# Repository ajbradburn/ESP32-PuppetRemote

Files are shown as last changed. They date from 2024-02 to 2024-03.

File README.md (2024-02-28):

The goal is to create a remote control for a puppet.

1. Direct communication between two ESP devices via ESP-NOW.
2. Playing sound upon trigger.
3. Control servo to articulate eye lids.
4. Control motor to retract wings.

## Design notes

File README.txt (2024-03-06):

The goal is to create a remote control for a puppet.

1. Direct communication between two ESP devices via ESP-NOW.
2. Playing sound upon trigger.
3. Control servo to articulate eye lids.
4. Control motor to retract wings.

Implemented with Micropython
https://micropython.org/download/ESP32_GENERIC_S3/

Example Ampy Commands: ampy -p /dev/ttyACM0 -b 115200 put receiver.py main.py

-: Setup Environment
-- THIS --
sudo apt install python3-venv
python3 -m venv .venv
source .venv/bin/activate
pip3 install adafruit-ampy
pip3 install esptool
-- OR --
sudo apt install python3 python3-pip
sudo pip3 install adafruit-ampy --break-system-packages
sudo pip3 install esptool –break-system-packages
-- THEN --
python3 -m esptool --port /dev/ttyACM0 erase_flash
python3 -m esptool --chip esp32s3 --port /dev/ttyACM0 write_flash -z 0 ESP32_GENERIC_S3-SPIRAM_OCT-20240222-v1.22.2.bin
ampy -p /dev/ttyACM0 -b 115200 put receiver.py main.py

To reset: -> Connect via serial port. picocom -b 115200 /dev/ttyACM0 -> At the terminal, type the following:
import machine
machine.reset()

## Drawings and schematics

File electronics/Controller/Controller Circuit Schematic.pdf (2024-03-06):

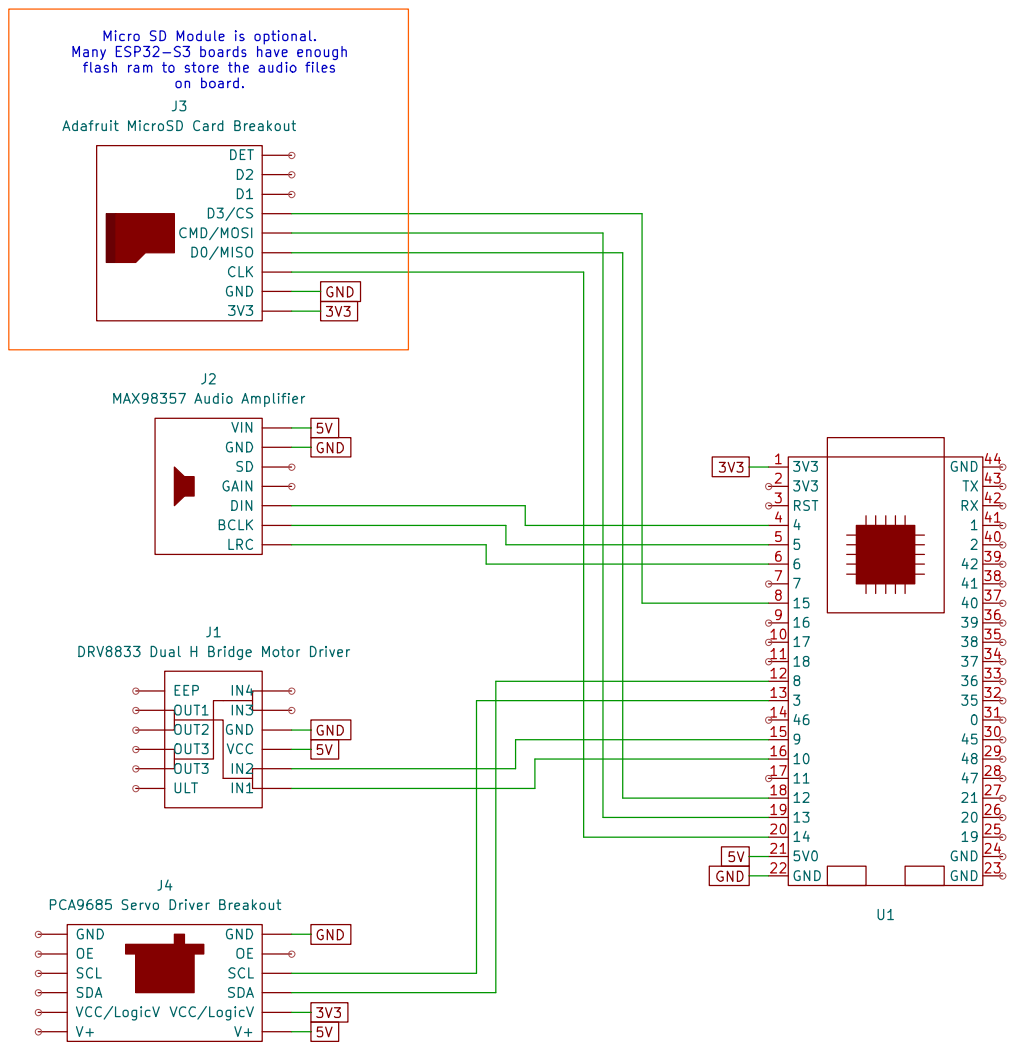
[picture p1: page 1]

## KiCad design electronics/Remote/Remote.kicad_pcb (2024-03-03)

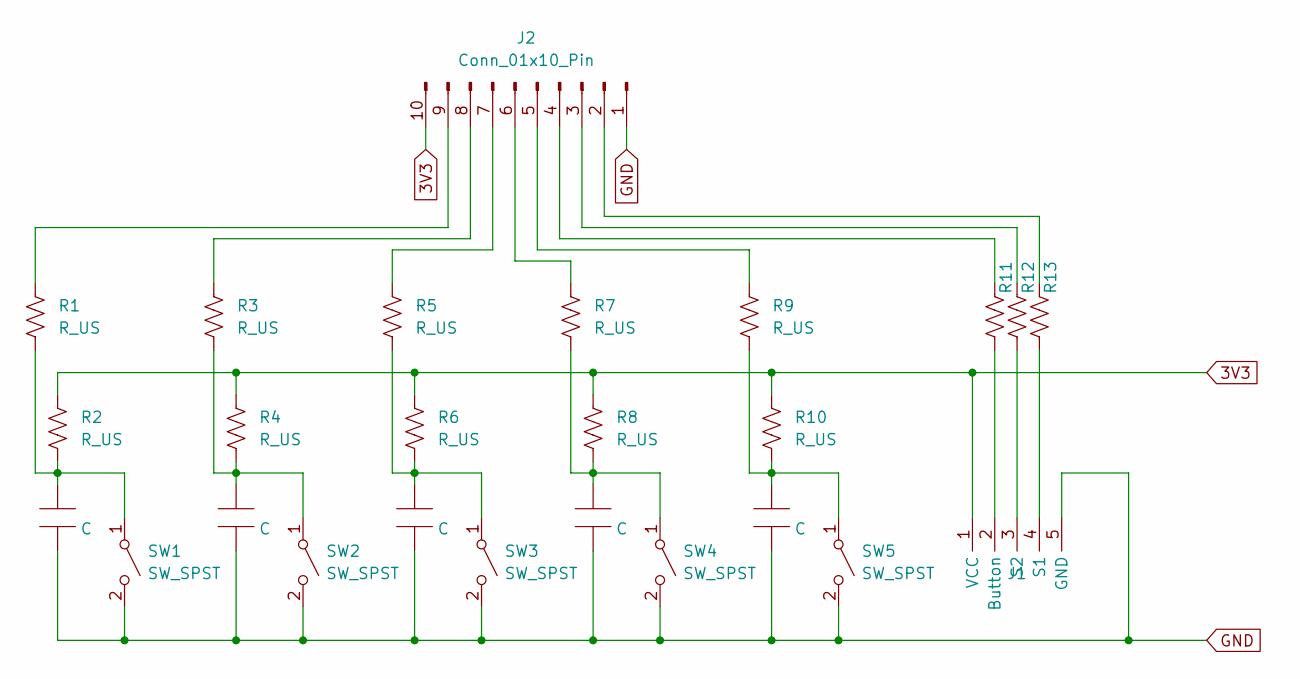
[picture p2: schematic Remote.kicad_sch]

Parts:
C1, C2, C3, C4, C5: C; C_MicroMELF_MMU-0102
J1: PinHeader_1x05_P2.54mm_Vertical
J2: Conn_01x10_Pin; PinHeader_1x10_P2.54mm_Vertical
R1, R2, R3, R4, R5, R6, R7, R8, R9, R10, R11, R12, R13: R_US; R_0805_2012Metric
SW1, SW2, SW3, SW4, SW5: SW_SPST; SW_Push_1P1T_NO_6x6mm

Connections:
3V3: J1.1 (VCC), J2.10, R2.1, R4.1, R6.1, R8.1, R10.1
GND: C1.1, C2.1, C3.1, C4.1, C5.1, J1.5 (GND), J2.1, SW1.2 (B), SW2.2 (B), SW3.2 (B), SW4.2 (B), SW5.2 (B)
unnamed: J1.2 (Button), R11.2
unnamed: J1.4 (S1), R13.2
unnamed: J1.3 (S2), R12.2
unnamed: J2.2, R13.1
unnamed: J2.3, R12.1
unnamed: J2.4, R11.1
unnamed: J2.5, R9.1
unnamed: J2.6, R7.1
unnamed: J2.7, R5.1
unnamed: J2.8, R3.1
unnamed: J2.9, R1.1
unnamed: C1.2, R1.2, R2.2, SW1.1 (A)
unnamed: C2.2, R3.2, R4.2, SW2.1 (A)
unnamed: C3.2, R5.2, R6.2, SW3.1 (A)
unnamed: C4.2, R7.2, R8.2, SW4.1 (A)
unnamed: C5.2, R9.2, R10.2, SW5.1 (A)

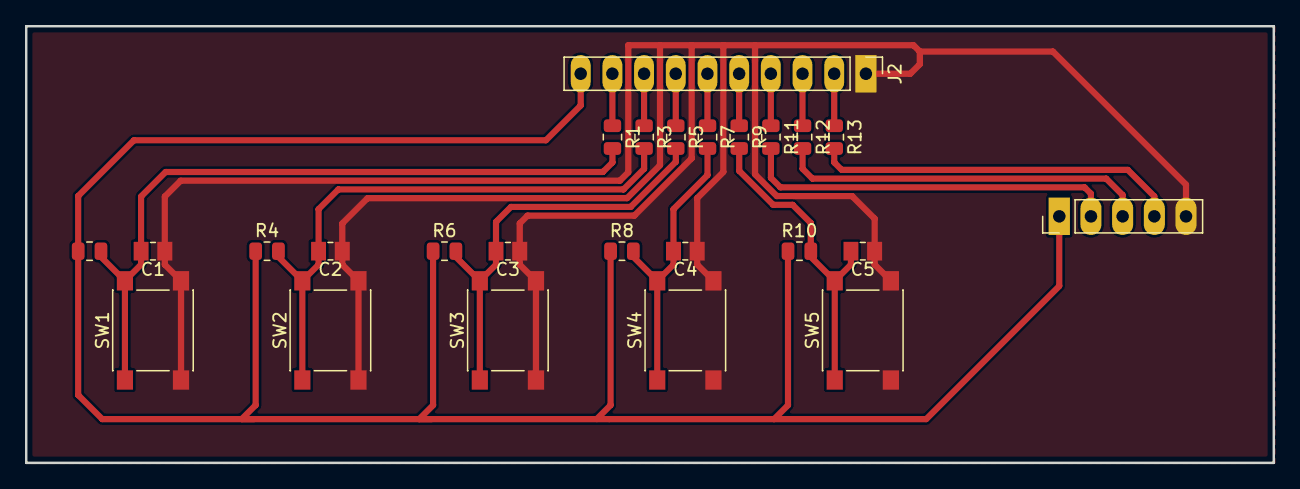
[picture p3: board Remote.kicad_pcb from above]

Board: 2 copper layers, 100.0 x 35.0 mm, 25 parts (0 on the bottom side), 18 nets.

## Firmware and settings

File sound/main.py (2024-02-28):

# The MIT License (MIT)
# Copyright (c) 2020 Mike Teachman
# https://opensource.org/licenses/MIT

# Purpose:
# - read 16-bit audio samples from a mono formatted WAV file on SD card
# - write audio samples to an I2S amplifier or DAC module 
#
# Sample WAV files in wav_files folder:
#   "taunt-16k-16bits-mono.wav"
#   "taunt-16k-16bits-mono-12db.wav" (lower volume version)
#
# Hardware tested:
# - MAX98357A amplifier module (Adafruit I2S 3W Class D Amplifier Breakout)
# - PCM5102 stereo DAC module
#
# The WAV file will play continuously until a keyboard interrupt is detected or
# the ESP32 is reset
  
from machine import I2S
from machine import SDCard
from machine import Pin
import uos

#======= USER CONFIGURATION =======
#WAV_FILE = 'chimes.wav'
WAV_FILE = 'snake.wav'
#WAV_FILE = 'chimes-22050.wav'
SAMPLE_RATE_IN_HZ = 44100
#======= USER CONFIGURATION =======

bck_pin = Pin(5) 
ws_pin = Pin(6)  
sdout_pin = Pin(4)

# channelformat settings:
#     mono WAV:  channelformat=I2S.ONLY_LEFT
audio_out = I2S(
    1, 
    sck=bck_pin, ws=ws_pin, sd=sdout_pin, 
    mode=I2S.TX,
    bits=16,
    format=I2S.MONO, 
    rate=SAMPLE_RATE_IN_HZ,
    ibuf=1024
    )

# configure SD card:
# See [docs](https://docs.micropython.org/en/latest/library/machine.SDCard.html#esp32) for
# recommended pins depending on the chosen slot.
#   slot=2 configures SD card to use the SPI3 controller (VSPI), DMA channel = 2
#   slot=3 configures SD card to use the SPI2 controller (HSPI), DMA channel = 1
sd = SDCard(slot=3, sck=Pin(14), mosi=Pin(13), miso=Pin(12), cs=Pin(15))
print(sd)
uos.mount(sd, "/sd")
import os
print(os.listdir("/sd"))
wav_file = '/sd/{}'.format(WAV_FILE)
wav = open(wav_file,'rb')

# advance to first byte of Data section in WAV file
pos = wav.seek(44) 

# allocate sample arrays
#   memoryview used to reduce heap allocation in while loop
wav_samples = bytearray(1024)
wav_samples_mv = memoryview(wav_samples)
audio_out.shift

print('Starting')
# continuously read audio samples from the WAV file 
# and write them to an I2S DAC
try:
    while True:
        num_read = wav.readinto(wav_samples_mv)
        if num_read == 0:
            break
        num_written = 0
        while num_written < num_read:
            num_written += audio_out.write(wav_samples_mv[num_written:num_read])
except:
    print('caught exception {} {}'.format(type(e).__name__, e))


'''
while True:
    try:
        num_read = wav.readinto(wav_samples_mv)
        num_written = 0
#        # end of WAV file?
        if num_read == 0:
#            # advance to first byte of Data section
            pos = wav.seek(44) 
        else:
#            # loop until all samples are written to the I2S peripheral
            while num_written < num_read:
                num_written += audio_out.write(wav_samples_mv[num_written:num_read])
    except (KeyboardInterrupt, Exception) as e:
        print('caught exception {} {}'.format(type(e).__name__, e))
        break
'''
    
wav.close()
uos.umount("/sd")
sd.deinit()
audio_out.deinit()
print('Done')

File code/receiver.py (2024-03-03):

import network
import espnow

import ubinascii
print('Device MAC Address:')
print(network.WLAN().config('mac'))
print(ubinascii.hexlify(network.WLAN().config('mac'),':').decode())

from machine import I2C, Pin, I2S, SDCard, Timer
from servo import Servos
import time
from uos import mount, umount
from os import listdir
from time import ticks_ms, ticks_diff
from math import fabs

# Start ESP NOW
# A WLAN interface must be active to send()/recv()
sta = network.WLAN(network.STA_IF)
sta.active(True)

e = espnow.ESPNow()
e.active(True)
# End ESP NOW

# Start Servo Config
# Connect to the PCA9685 servo driver.
servo_disable_time = None

i2c = I2C(0, scl=3, sda=8)
ser = Servos(i2c, address=0x40)
ser.position(0, 0)
print(ser) # CRITICALLY IMPORTANT. This print statement enables I2S to work properly. Some combination of the i2c assignment, and then a variable assignemtn afterwards makes the I2S sound terrible. Simply printing the variable resolves the issue...
# End Servo

# Start Motor Config
# Configure the forward and reverse pins.
motor_disable_time = None

mf = Pin(9, Pin.OUT) # Motor Forward
mb = Pin(10, Pin.OUT) # Motor Backward
# End Motor

# Start Sound Config
current_file = None
BUFFER_SIZE = 10000

# Configure the I2S connection to the Max98357A audio amplifier.
bclk = Pin(5) # Clock Pin
lrc = Pin(6) # Channel Select Pin
din = Pin(4) # Data Pin

audio_out = I2S(
    1, 
    sck=bclk, ws=lrc, sd=din, 
    mode=I2S.TX,
    bits=16,
    format=I2S.MONO, 
    rate=44100,
    ibuf=BUFFER_SIZE
    )

# Start SD Card
# Connect to the SD card reader via SPI.
sd = SDCard(slot=3, sck=Pin(14), mosi=Pin(13), miso=Pin(12), cs=Pin(15))
mount(sd, "/sd")
#print(os.listdir("/sd"))

def blink():
    global servo_disable_time
    if servo_disable_time == None:
        servo_disable_time = ticks_ms() + 1000
        ser.position(0, 180)
    else:
        if servo_disable_time < ticks_ms():
            servo_disable_time = None
            ser.position(0, 0)

def flap():
    global motor_disable_time
    if motor_disable_time == None:
        motor_disable_time = ticks_ms() + 1000
        mf.value(1)
        print('Starting Flap')
    elif motor_disable_time < ticks_ms():
        if mf.value():
            motor_disable_time = ticks_ms() + 1000
            mf.value(0)
            mb.value(1)
            print('Reversing Flap')
        elif mb.value():
            motor_disable_time = None
            mb.value(0)
            print('Done Flapping')
        else:
            print('Already flapping.')

def i2s_callback(arg):
    global current_file
    global BUFFER_SIZE
    wav_samples = bytearray(BUFFER_SIZE)
    wav_samples_mv = memoryview(wav_samples)
    num_read = current_file.readinto(wav_samples_mv)
    if num_read == 0:
        audio_out.irq(None)
        current_file.close()
        current_file = None
    else:
        audio_out.write(wav_samples_mv[:num_read])

def playAudio(file):
    global current_file
    global BUFFER_SIZE
    # If the audio file has a value, we are going to abort, and let it finish.
    if current_file != None:
        return

    # Open the file and seek data.
    wav_file = '/sd/{}'.format(file)
    current_file = open(wav_file,'rb')
    pos = current_file.seek(44) 

    # Allocate audio buffer.
    #   memoryview used to reduce heap allocation in while loop
    wav_samples = bytearray(BUFFER_SIZE)
    wav_samples_mv = memoryview(wav_samples)
    #audio_out.shift
    num_read = current_file.readinto(wav_samples_mv)
    audio_out.irq(i2s_callback)
    audio_out.write(wav_samples_mv[:num_read])

def upkeep():
    if servo_disable_time != None:
        blink()
    if motor_disable_time != None:
        flap()

# Application Loop
while True:
    upkeep()

    host, msg = e.recv(0)
    if msg:             # msg == None if timeout in recv()
        #print(host, msg)
        command = msg.decode('utf-8')
        if msg == b'8':
            print('Play Audio')
            playAudio('snake.wav')
        elif msg == b'3':
            print('Blink')
            blink()
        elif msg == b'46':
            print('Flap Wings')
            flap()
        elif msg == b'9':
            print('No action assigned to command 9.')
        elif msg == b'10':
            print('No action assigned to command 10')

umount("/sd")
sd.deinit()
audio_out.deinit()

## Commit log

2024-02-29 I have a working servo and motor control.
2024-02-29 Added a schematic for a basic button board.
    [Controller.kicad_pcb, Controller.kicad_sch, Remote.kicad_pcb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]
2024-03-01 I have a mostly working receiver. I need to sort out audio playback. Wifi is enabled with ESPNow, and I think that might be the cause of this issue. I'll do some testing.
    [receiver.py, sender.py, sound_test.py]
2024-03-02 I have a working proof-of-concept for the remote control. There is a bug I've identified. Something about initializing I2C, and then assigning a variable afterwards causes issues with I2S output. Add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
    Right now, the variable is calling a servo object from a 3rd
    party library, but that isn't important. making my own function, and
    calling that function will produce the same result.
    [receiver.py]
2024-03-02 Working on making a script that can be submitted as part of a bug report.
    [sound_test.py]
2024-03-02 sound_test.py is a stripped down demonstration of the bug.
    [sound_test.py]
2024-03-02 Two stripped down examples of the bug, one with blocking, the other with non-blocking implimentation.
    [sound_test.py, sound_test2.py]
2024-03-03 Fixed some issues with the flap or blink function being called before a previous operation was called.
    [receiver.py]
2024-03-03 Basic remote button interface created.
    [Remote.kicad_pcb]
2024-03-06 Added a circuit schematic for the receiver/controller of electronics.
    [Controller.kicad_sch]
